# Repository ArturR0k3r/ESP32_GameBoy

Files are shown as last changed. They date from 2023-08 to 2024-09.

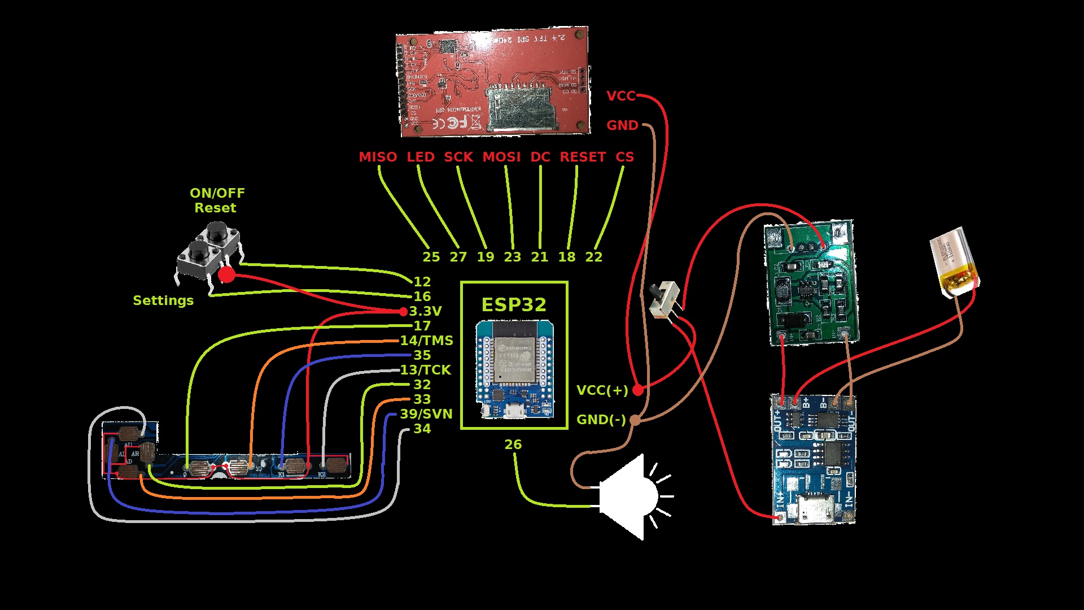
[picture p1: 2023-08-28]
0.HW/Circuit_Scematic.jpg

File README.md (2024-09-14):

# Pen_GameConsole

NintendoEntertainmentSystem Emulation on ESP32 and ILI9341 
#HW and Housing assembly



#Flashing the Software 
##1. Open ESPFlashDownloadTool_vXYZ.exe (Download Link: https://www.espressif.com/sites/default/files/tools/flash_download_tools_v3.6.4_0.rar)
		!!!If you work with mingw and esp idf and you get problems after using the ESPFlashTool (in my case, make doesn't work) go to!!!
		!!!the msys32 directory (<-"root" of msys/mingw) and run the autorebase.bat script...for me, after this everything works fine!!!
##2. Choose Button "ESP32 DownloadTool"
##3. Choose files to upload (Box with |...|) write adress to flash behind the @	
	first file 		bootloader.bin		0x1000
	second file		partitions.bin		0x8000
	3. file			nesemu.bin			0x10000
	4. file			roms.txt			0x68000		!you've to change the file according your needs - otherwise you can only choose 3 roms!
	5. file			yourRom.nes			0x69000		!make sure the roms are not greater than the partition-size.		
	6. file			yourNextRom.nes		0x.....
	7. file			yourNextRom2.nes	0x.....
		.
		.
		.
		
		Flash the Roms to this Adresses
	No.		  Adress 		Size(up to...KB)	
	rom01 	  0x69000			100
	rom02	  0x82000			260
	rom03	  0xc3000			388
	rom04	 0x124000			132
	rom05    0x145000			260
	rom06	 0x186000			100
	rom07	 0x19f000			100
	rom08	 0x1b8000			100
	rom09	 0x1d1000			772
	rom10	 0x292000			516
	rom11	 0x313000			296
	rom12	 0x35d000			260
	rom13	 0x39e000			260
	rom14	 0x3df000			132	

##4.	Choose the following Settings

		SPI SPEED: 40MHz

		SPI MODE: DIO

		FLASH SIZE: 32Mbit(=4MB)

		COM: can be found in Device Manager
		
##5.	Press "Start", when finished "Stop"
	After a Reset/Restart(dis-reconnect the USB) the Emulator works

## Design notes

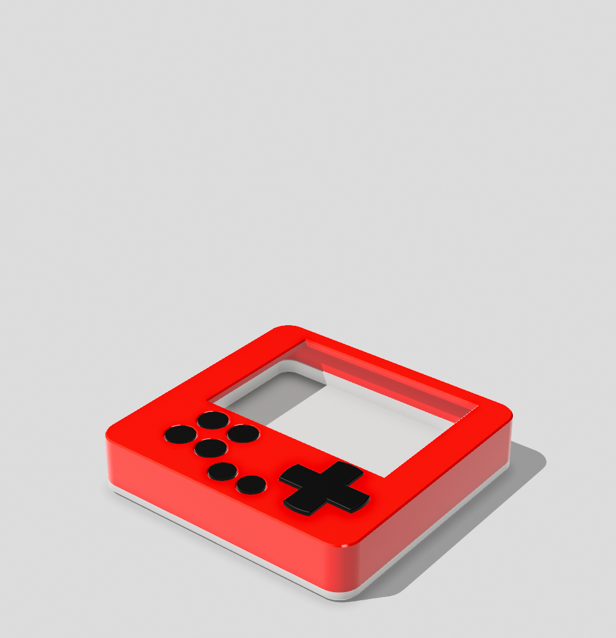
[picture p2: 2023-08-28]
2.IndustrialDesign-3D Models/Screenshot 2023-08-15 111055.png

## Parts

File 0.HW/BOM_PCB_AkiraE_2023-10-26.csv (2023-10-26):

ID | Name | Designator | Footprint | Quantity | Manufacturer Part | Manufacturer | Supplier | Supplier Part | Price
1 | 100nF | C4,C6,C8 | C0805 | 3 | CC0805KRX7R9BB104 | YAGEO | LCSC | C49678 | 0.005
2 | AMS1117-3.3 | U2 | SOT-223-3_L6.5-W3.4-P2.30-LS7.0-BR | 1 | AMS1117-3.3 | AMS | LCSC | C6186 | 0.141
3 | ESP32 | U1 | WIFIM-SMD_38P-L19.2-W18.0-P1.27 | 1 | ESP32 |  | LCSC | C328062 | 3.296
4 | 470Ω | R3,R2 | R0805 | 2 | 0805W8F4700T5E | UniOhm | LCSC | C17710 | 0.002
5 | 10K | R7,R6,R5,R4,R1 | R0805 | 5 | 0805W8F1002T5E | UniOhm | LCSC | C17414 | 0.001
6 | YELLOW | D2 | LED0805-RD | 1 | 17-21SUYC/TR8 | KENTO | LCSC | C2296 | 0.012
7 | 1uF | C5 | C0805 | 1 | CL21B105KBFNNNE | SAMSUNG | LCSC | C28323 | 0.01
8 | 10uF | C1,C2,C3,C7 | C0805 | 4 | CL21A106KAYNNNE | SAMSUNG | LCSC | C15850 | 0.011
9 | RESET | SW1 | SW-SMD_4P-L5.1-W5.1-P3.70-LS6.5-TL-2 | 1 | TS-1187A-B-A-B | XKB Enterprise | LCSC | C318884 | 0.016
10 | Header-Male-2.54_1x5 | P1 | HDR-5X1/2.54 | 1 | Header-Male-2.54_1x5 | LCSC
11 | STATUS (BLUE) | D1 | LED0603-R-RD | 1 | 19-217/BHC-ZL1M2RY/3T | EVERLIGHT | LCSC | C72041 | 0.018
12 | Photoresistor-5528 | PHOTORESISTOR1 | SNR2-3.0 | 1 | Photoresistor-5528
13 | 100kΩ | R10 | R1206 | 1 | RTT06472JTP | RALEC(旺诠) | LCSC | C104821 | 0.003
14 | HDR-M-2.54_1x8 | J1 | HDR-M-2.54_1X8 | 1 |  |  | LCSC | C190820 | 0.051
15 | BUZZER | BUZZER1 | BUZ-TH_BD12.0-P6.00-D0.9-RD | 1 | buzzer | null | LCSC | C9900014030
16 | MMBT2222A_C466638 | Q1 | SOT-23-3_L2.9-W1.4-P1.90-LS2.6-BR | 1 | MMBT2222A | High Diode(海德) | LCSC | C466638 | 0.018
17 | 470Ω | R14 | R1206 | 1 | RTT06472JTP | RALEC(旺诠) | LCSC | C104821 | 0.003
18 | BUTTON_C9900016052 | KEY9,KEY1,KEY2,KEY3,KEY4,KEY5,KEY7,KEY8,KEY6 | SW-SMD_4P-L5.1-W5.1-P3.70-LS6.5-TL-2 | 9 | button | null | LCSC | C9900016052
19 | 2.4_TFT_ILI9341_symbol | DISPLAY1 | ILI9341_320X240_TFT_LCD | 1 |  |  | Nettigo | ili9341-24-touch
20 | TL3330AF260QG | SW3 | SW-SMD_E-SWITCH_TL3330 | 1 | TL3330AF260QG | E-Switch | LCSC | C2886886 | 0.352
21 | HDR-M-2.54_1x2 | SOUND1 | HDR-M-2.54_1X2 | 1 |  |  | LCSC | C124375 | 0.022

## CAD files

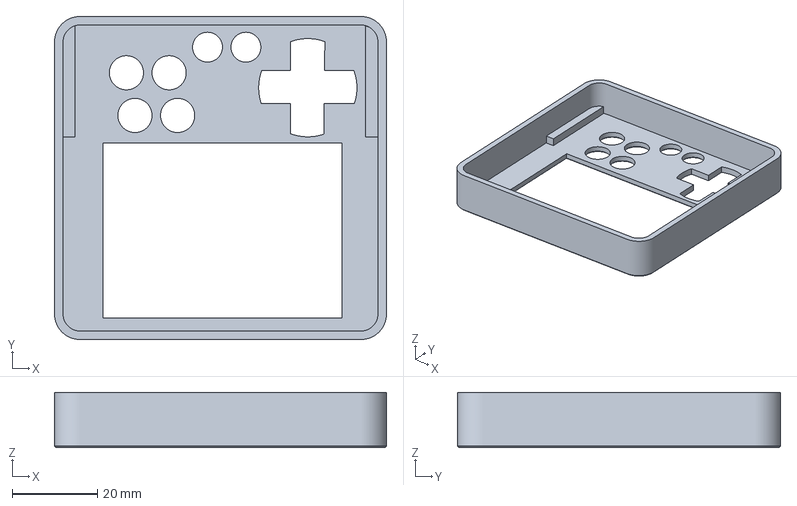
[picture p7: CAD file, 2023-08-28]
2.IndustrialDesign-3D Models/NES Top.3mf
77.8 x 75.7 x 13.0 mm

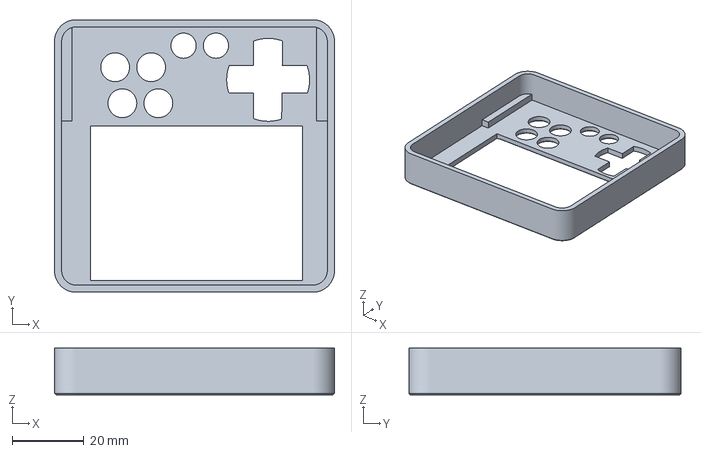
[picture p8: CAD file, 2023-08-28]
2.IndustrialDesign-3D Models/NES Top2.4.3mf
77.8 x 75.7 x 13.0 mm

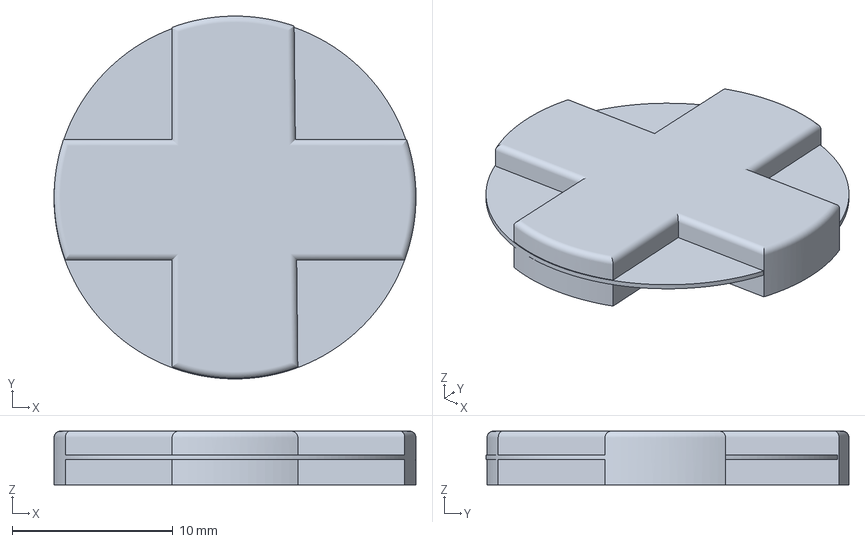
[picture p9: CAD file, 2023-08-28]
2.IndustrialDesign-3D Models/NES Button Cross.3mf
22.6 x 22.6 x 3.35 mm

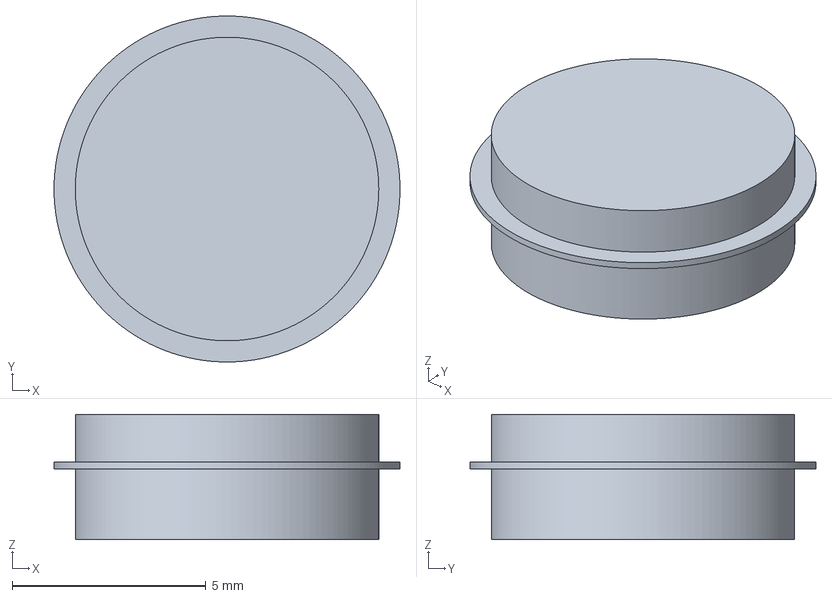
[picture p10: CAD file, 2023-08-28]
2.IndustrialDesign-3D Models/NES Button Round Big.3mf
8.94 x 8.94 x 3.23 mm

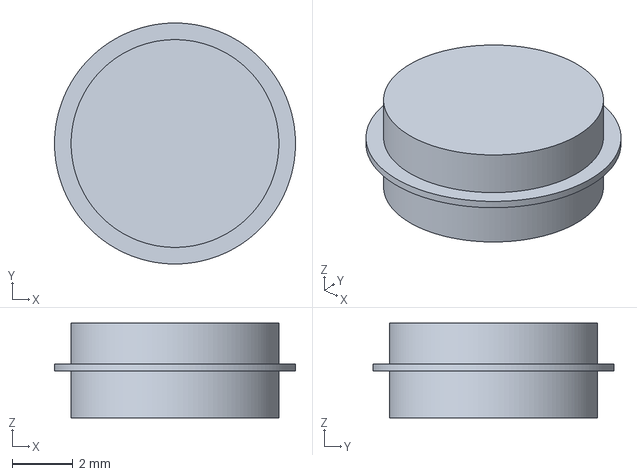
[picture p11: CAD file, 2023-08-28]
2.IndustrialDesign-3D Models/NES Button Round Small.3mf
7.96 x 7.96 x 3.14 mm

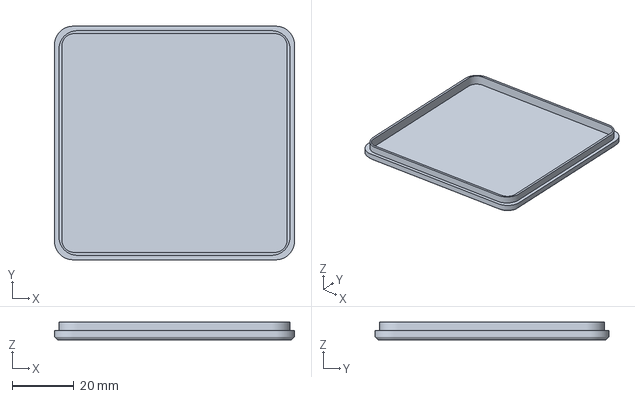
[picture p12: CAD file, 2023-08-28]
2.IndustrialDesign-3D Models/NES Bottom.3mf
77.8 x 75.7 x 5.80 mm

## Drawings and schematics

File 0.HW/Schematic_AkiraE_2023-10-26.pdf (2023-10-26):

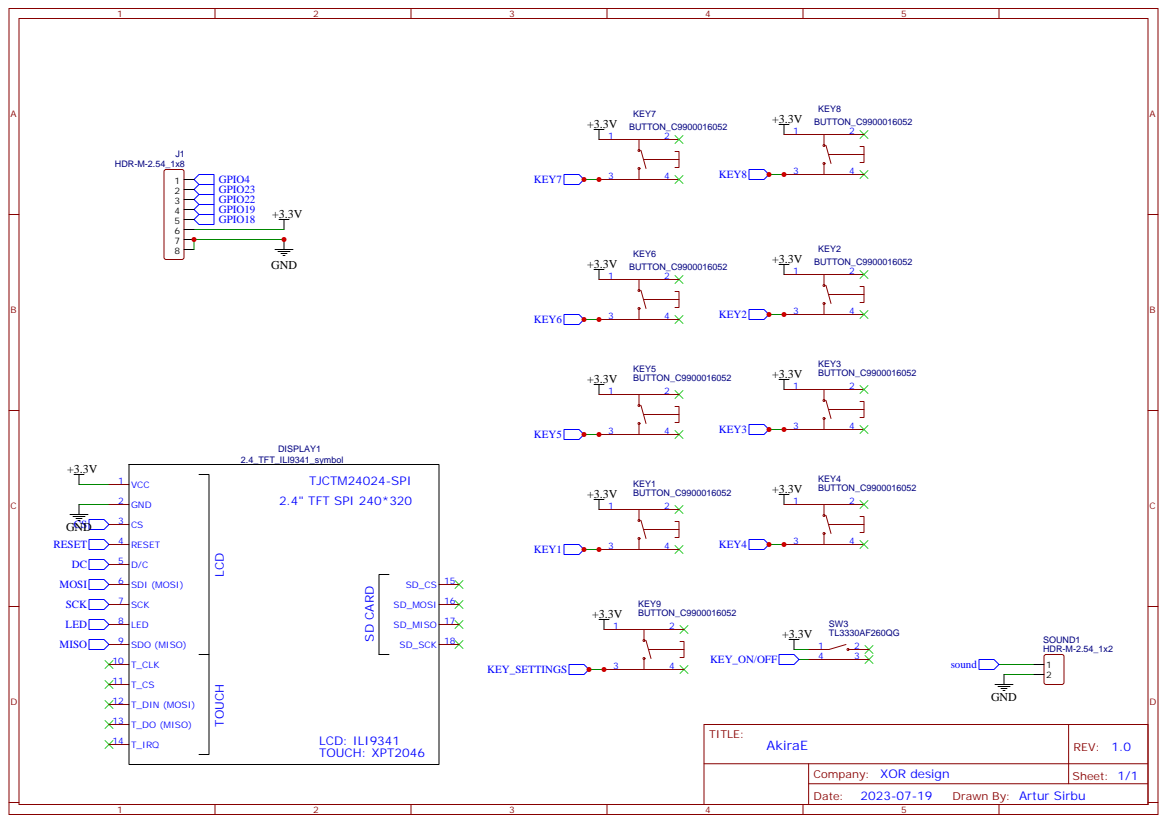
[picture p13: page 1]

IO0 25 IO4 26 IO16 27 IO17 28 IO5 29 IO18 30 IO19 31 NC 32 IO21 33 RXD0 34 TXD0 35 IO22 36 IO23 37 GND 38

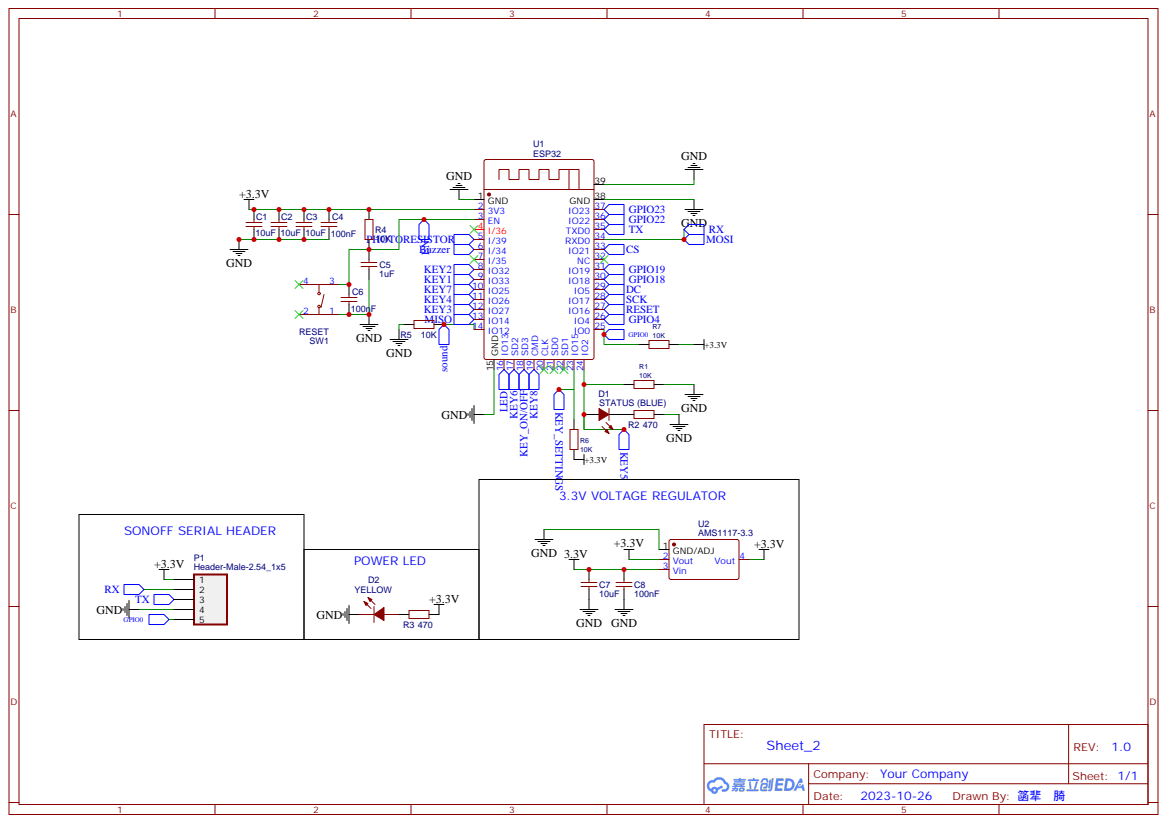
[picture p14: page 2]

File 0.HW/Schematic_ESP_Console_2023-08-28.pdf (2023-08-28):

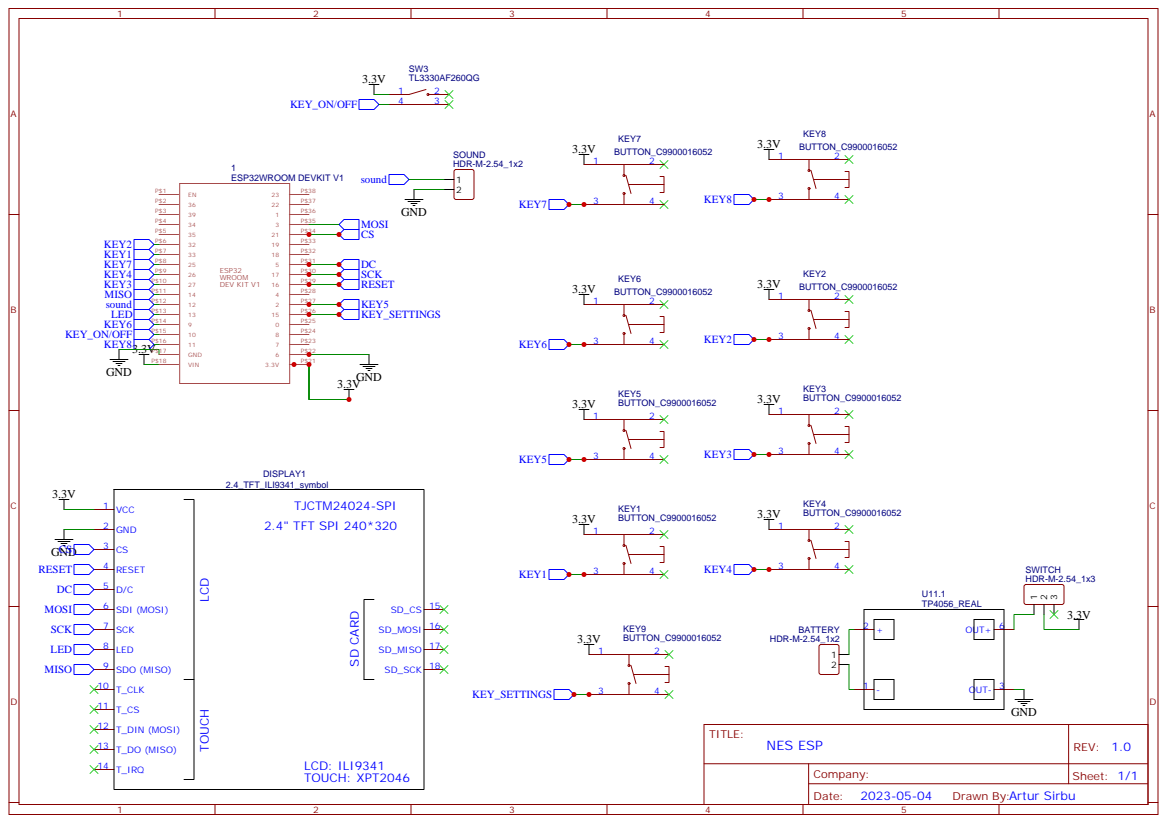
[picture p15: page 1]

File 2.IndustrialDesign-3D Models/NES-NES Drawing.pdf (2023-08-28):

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

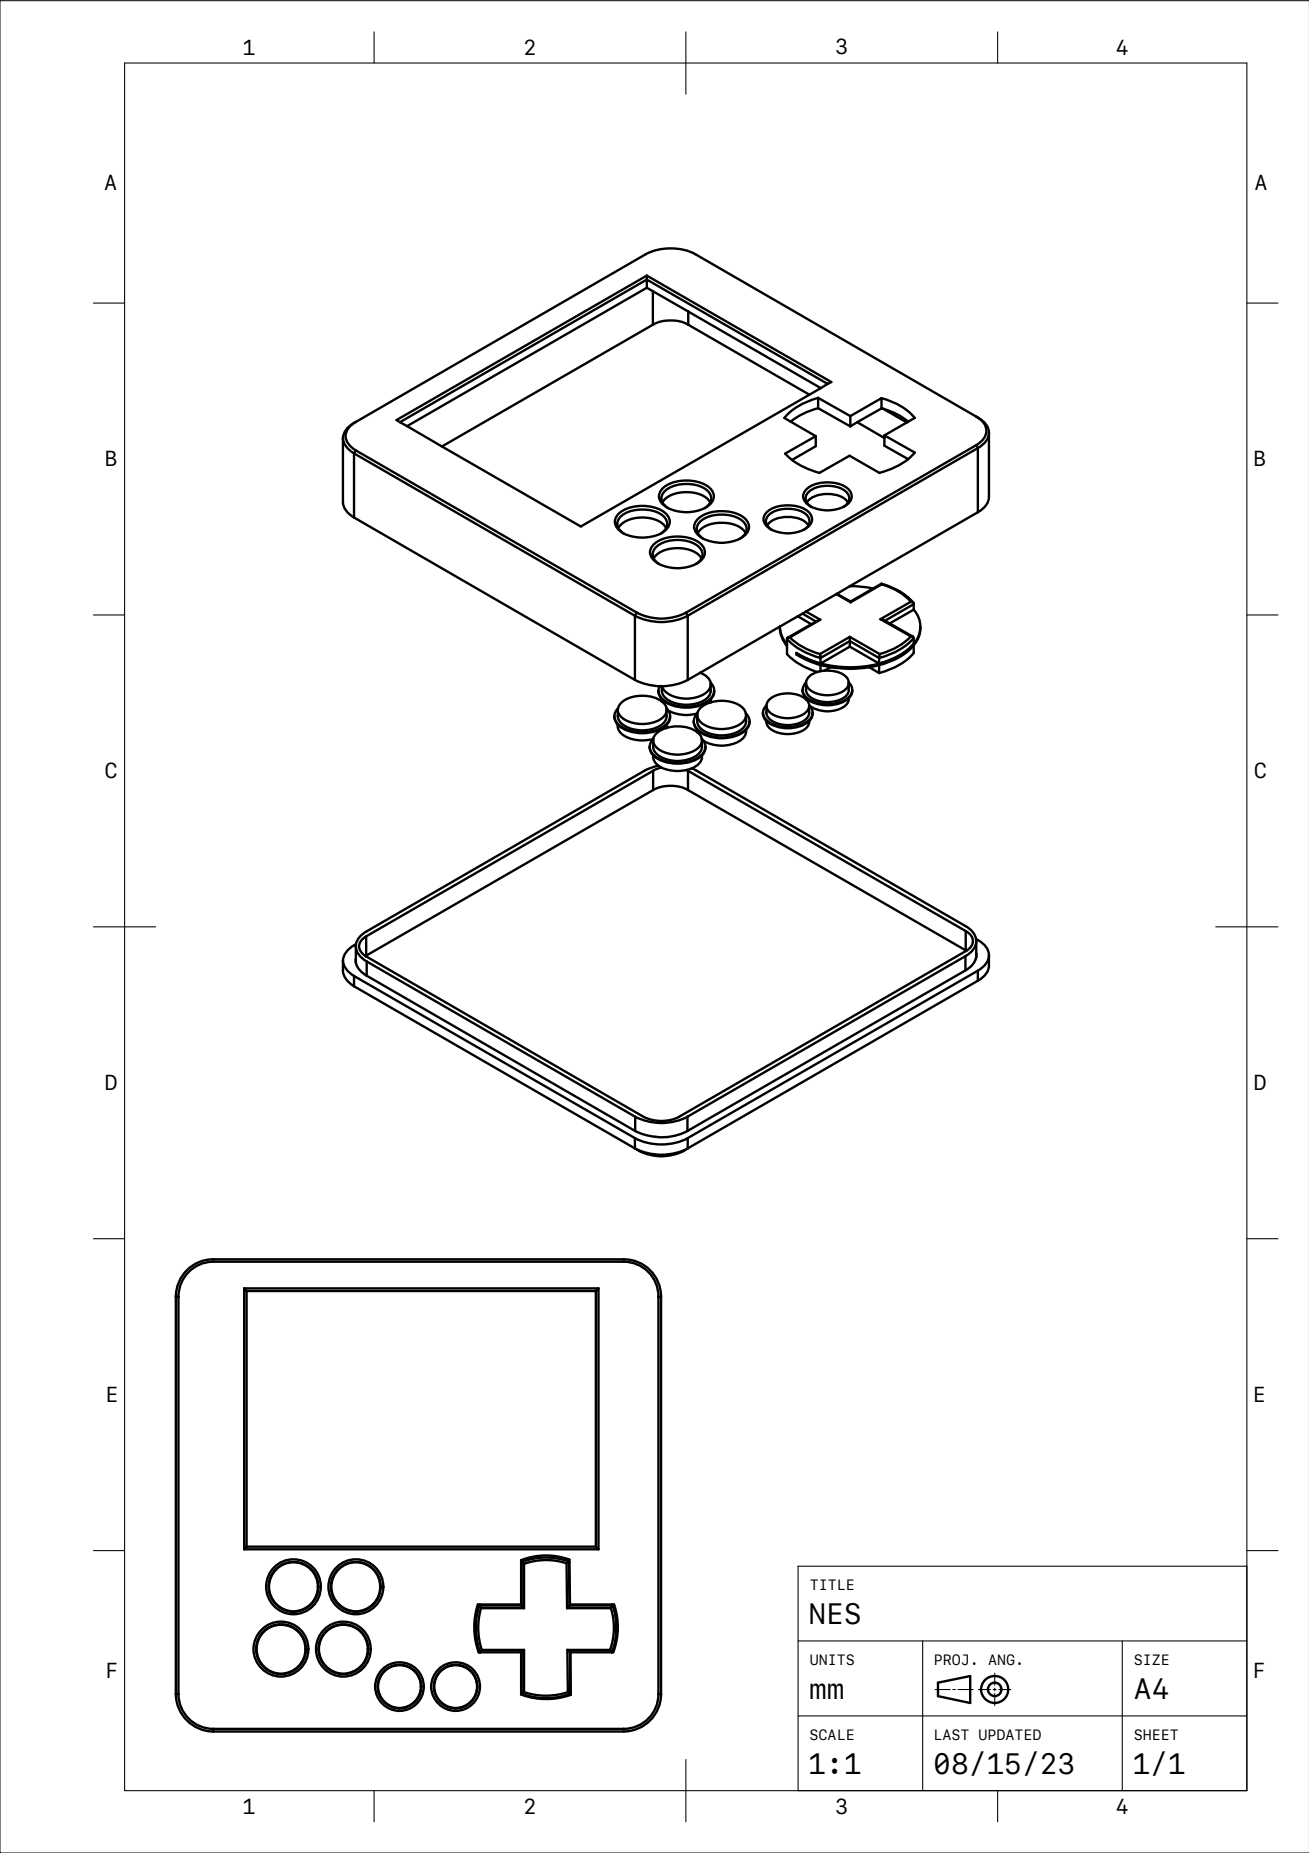
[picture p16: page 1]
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

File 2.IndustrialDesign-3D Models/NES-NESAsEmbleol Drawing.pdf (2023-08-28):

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

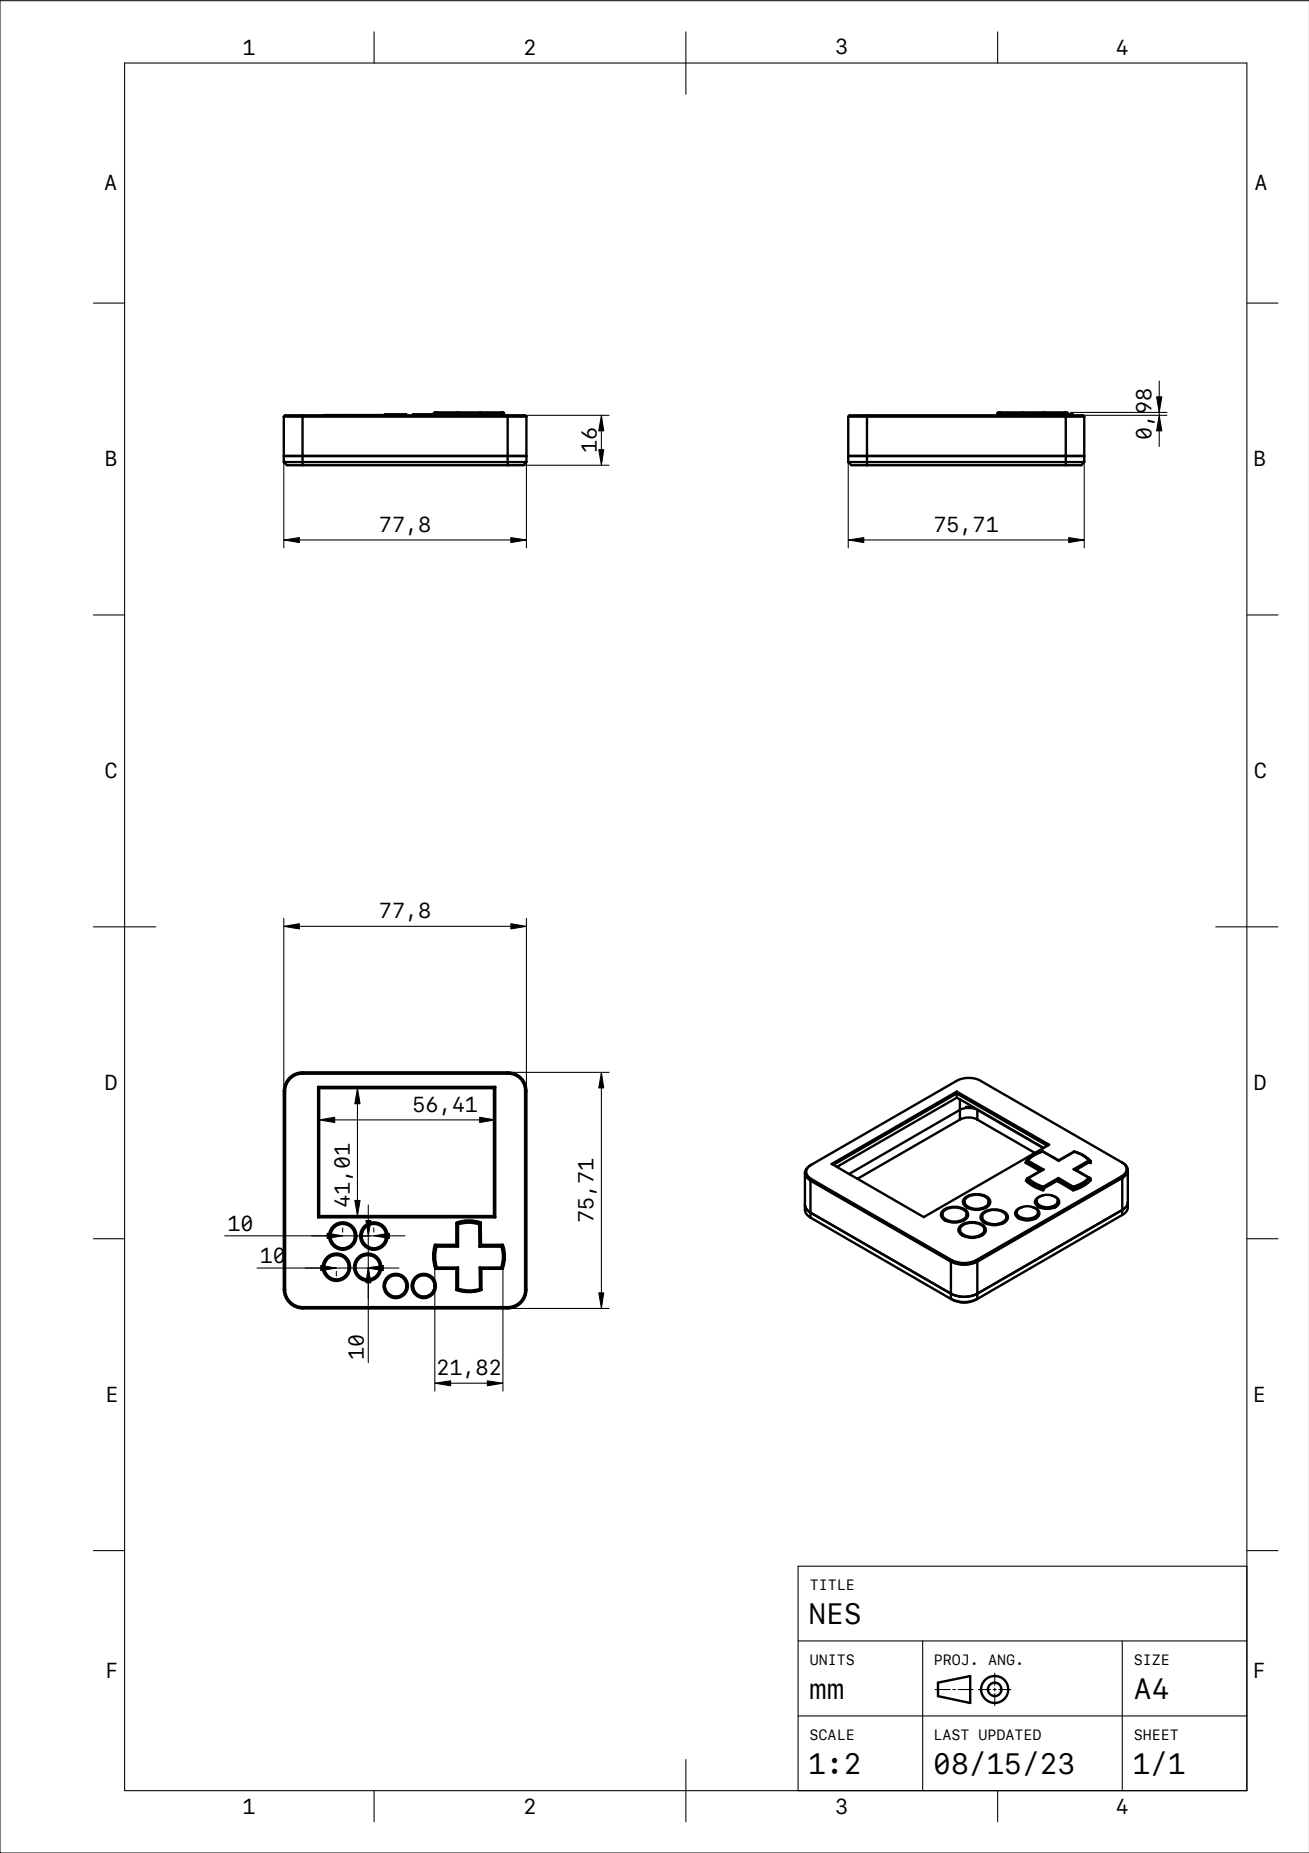
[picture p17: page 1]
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
